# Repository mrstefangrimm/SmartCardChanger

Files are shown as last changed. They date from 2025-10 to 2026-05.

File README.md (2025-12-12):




# Smart Card Changer

The Smart Card Changer gives remote access to up to five smart cards, such as access or bank cards, using a single smart card reader. This repository contains the software, the hardware and the mechanical design files.

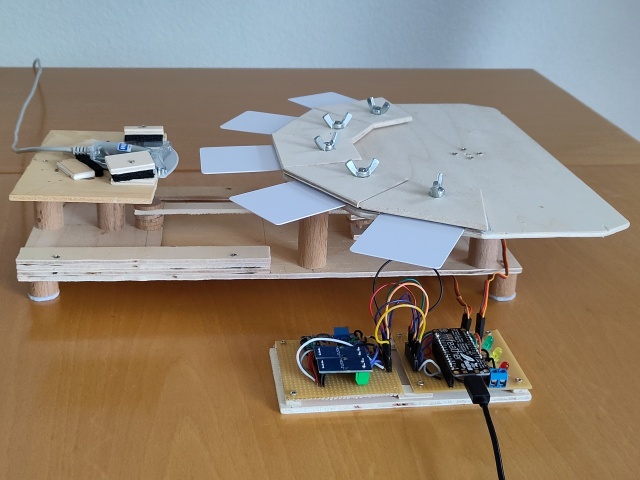
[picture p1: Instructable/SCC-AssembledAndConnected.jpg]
Assembled Smart Card Changet


## Getting Started

To use the software, you will have to build a device. How to build one is described in an [instructable](https://www.instructables.com/Smart-Card-Changer/).

## Examples

## Tests
Unit tests cover only basic functionality. The unit tests are part of the WinSccApp Visual Studio solution.

## Software Toolchain

**Built Applications**

| Application | License |
| --- | --- |
| SccApp | LGPL |
| CalibrationApp | LGPL |
| WinSccApp  | LGPL |

**Used Libraries**

| Library | Licence |
| :--- | --- |
| prfServo | LGPL |
| Adafruit MCP23017 Arduino Library | BSD |
| Adafruit BluefruitLE nRF51 | BSD |
| Arduino.h | LGPL |
| TemplateStateMachine | Apache License |
| .NET 8 | Microsoft license |

**Used Software Development Tools**

| Tool | License |
| --- | --- |
| Arduino IDE | GPL |
| Adafruit AVR Boards [Learn more](https://learn.adafruit.com/adafruit-feather-32u4-bluefruit-le/setup) | Adafruit license |
| avrdude | GPL |
| gcc | GPL |
| Visual Studio Community 2022 | Microsoft license |

## License

This is free software: you can redistribute it and/or modify it under the terms of the GNU Lesser General Public License as published by the Free Software Foundation, either version 3 of the License, or (at your option) any later version.

## Project History

The idea for the project came in mid 2025 and was first published on instructables.com in October 2025.

## Change History
See [github releases](https://github.com/mrstefangrimm/SmartCardChanger/releases).

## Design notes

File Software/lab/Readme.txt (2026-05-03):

Vipe Coded or Worse

What's vipe-coding: Fast, messy, duct‑tape code
What's worse: spaghetti coding

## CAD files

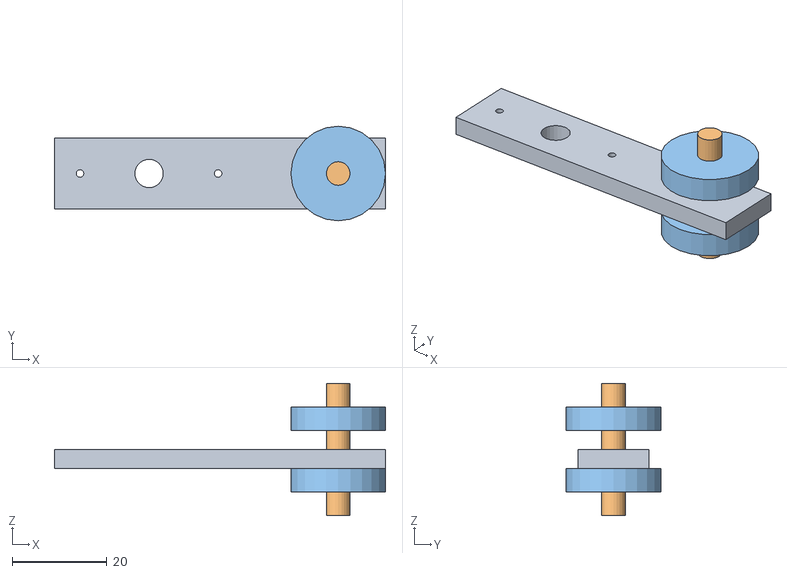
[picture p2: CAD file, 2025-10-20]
Software/src/scc/public/SCC-VirmsGroupServoArmWood.obj
70.0 x 20.0 x 28.0
SCC_ServoArm1
SCC_ServoArmJointBolt1
SCC_ServoArmJointFixation1

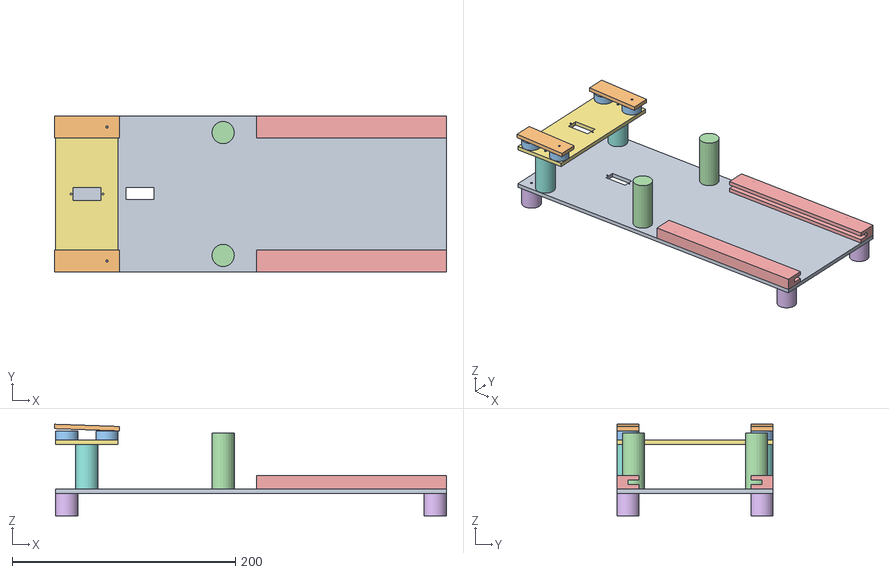
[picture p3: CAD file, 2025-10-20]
Software/src/scc/public/SCC-VirmsGroupStaticWood.obj
351.0 x 140.0 x 82.0
SCC_AdjustmentRamp_1_1
SCC_AdjustmentRamp_Distancer1
SCC_Base_Adjustment_Feet1
SCC_Base_Carriage_Rail1
SCC_Base_Feet_Wood_1_1
SCC_Rotation_Platform1
SCC_Rotation_Platform_Distancer1

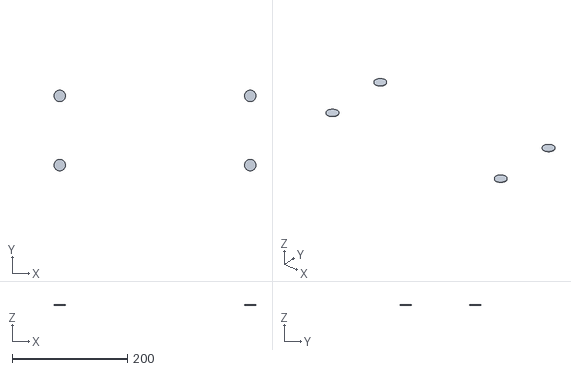
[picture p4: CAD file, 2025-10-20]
Software/src/scc/public/SCC-VirmsGroupStaticFelt.obj
350.0 x 140.0 x 2.00

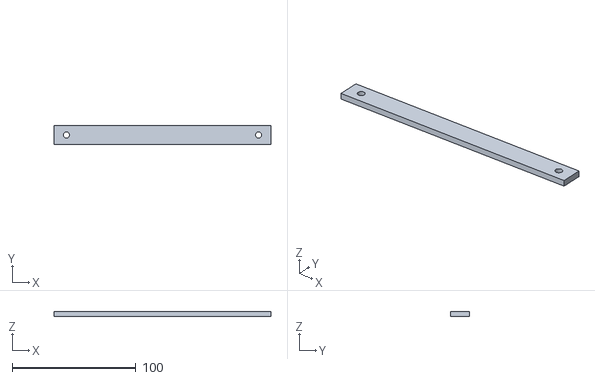
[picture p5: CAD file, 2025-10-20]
Software/src/scc/public/SCC-VirmsGroupServoArmExtensionWood.obj
175.0 x 15.0 x 4.00

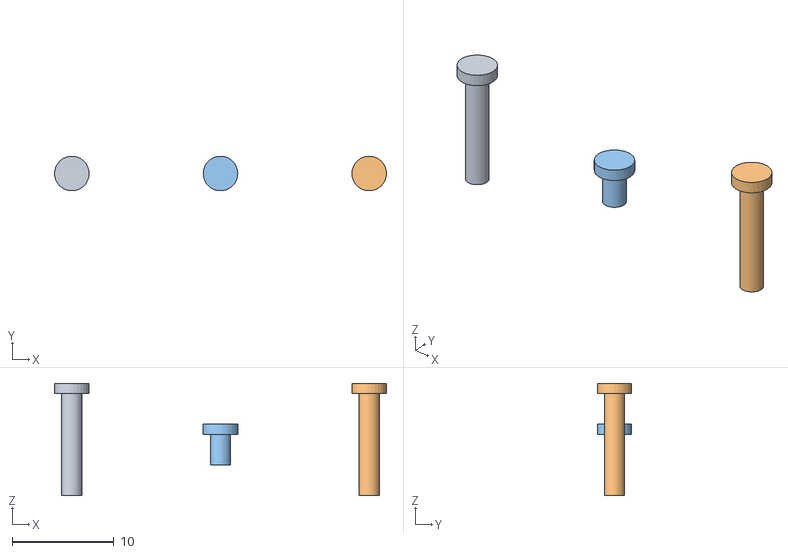
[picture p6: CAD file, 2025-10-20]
Software/src/scc/public/SCC-VirmsGroupServoArmSilver.obj
32.6 x 3.38 x 11.0
Lib_M2x10_1
Lib_M2x10_2
Lib_M2x3_1

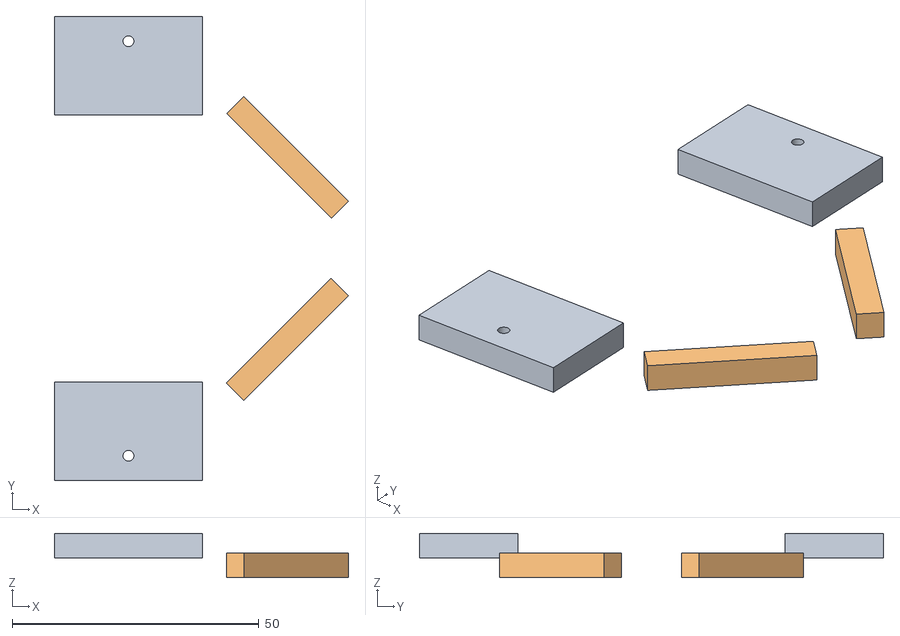
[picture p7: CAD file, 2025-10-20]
Software/src/scc/public/SCC-VirmsGroupCarriageAnthracite.obj
59.6 x 94.0 x 9.00
SCC_Carriage_Reader_Lid_Foam1
SCC_Carriage_Reader_Platform_Foam1

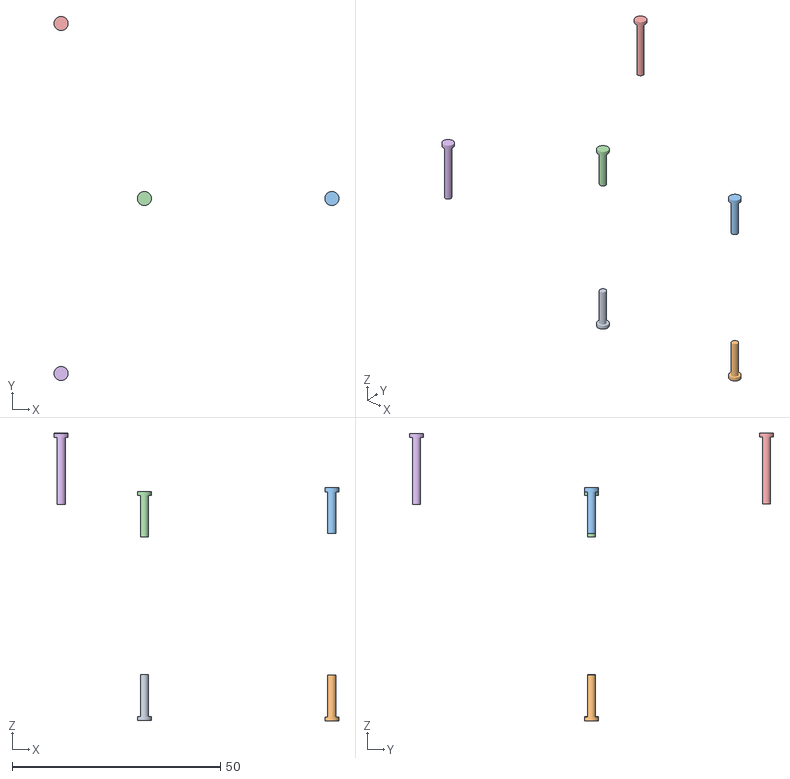
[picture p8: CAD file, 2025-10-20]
Software/src/scc/public/SCC-VirmsGroupCarriageSilver.obj
68.4 x 87.4 x 69.1
Lib_M2x10_1
Lib_M2x10_2
Lib_M2x10_3
Lib_M2x10_4
Lib_M2x16_1
Lib_M2x16_2

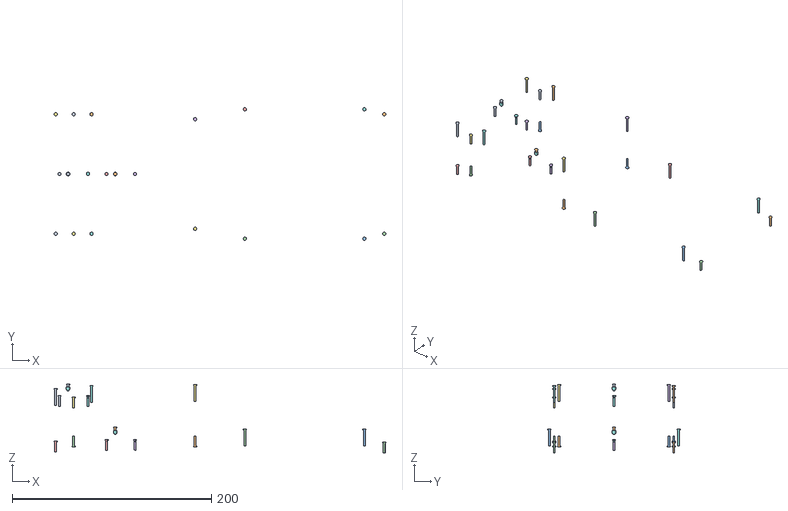
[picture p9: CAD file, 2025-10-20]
Software/src/scc/public/SCC-VirmsGroupStaticSilver.obj
333.4 x 133.4 x 69.0
Lib_M2x10_1
Lib_M2x10_10
Lib_M2x10_11
Lib_M2x10_12
Lib_M2x10_13
Lib_M2x10_14
Lib_M2x10_2
Lib_M2x10_3
Lib_M2x10_4
Lib_M2x10_5
Lib_M2x10_6
Lib_M2x10_7
Lib_M2x10_8
Lib_M2x10_9
Lib_M2x16_1
Lib_M2x16_10
Lib_M2x16_2
Lib_M2x16_3
Lib_M2x16_4
Lib_M2x16_5
Lib_M2x16_6
Lib_M2x16_7
Lib_M2x16_8
Lib_M2x16_9
Lib_M2x3_1
Lib_M2x3_2

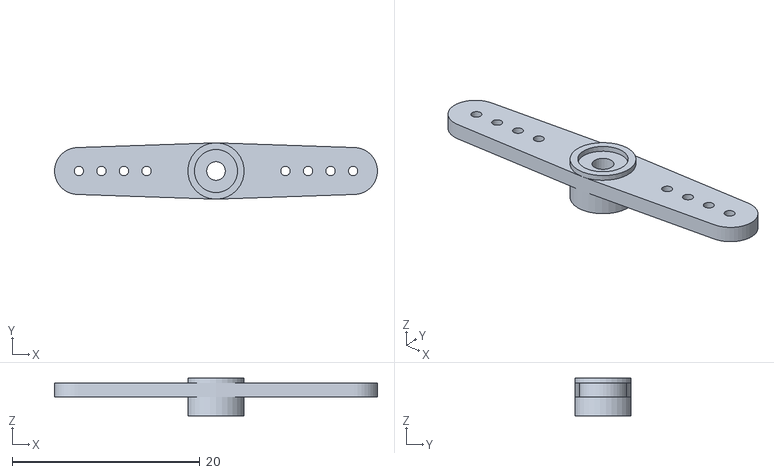
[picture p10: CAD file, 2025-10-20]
Software/src/scc/public/SCC-VirmsGroupServoArmWhite.obj
34.4 x 6.00 x 4.00

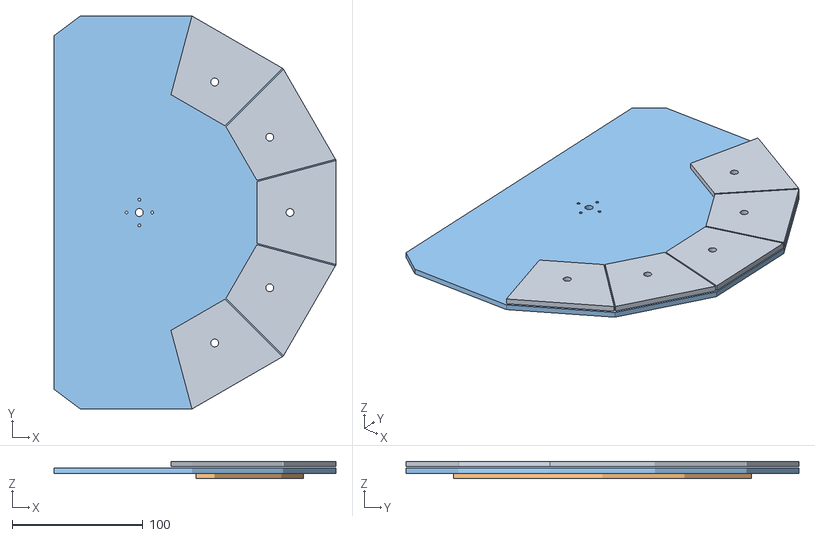
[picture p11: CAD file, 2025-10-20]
Software/src/scc/public/SCC-VirmsGroupRotatorWood.obj
215.0 x 300.0 x 13.0
SCC_Rotatator_Lid_Wood1
SCC_Rotatator_SkrewHolder1
SCC_Rotatator_Wood1

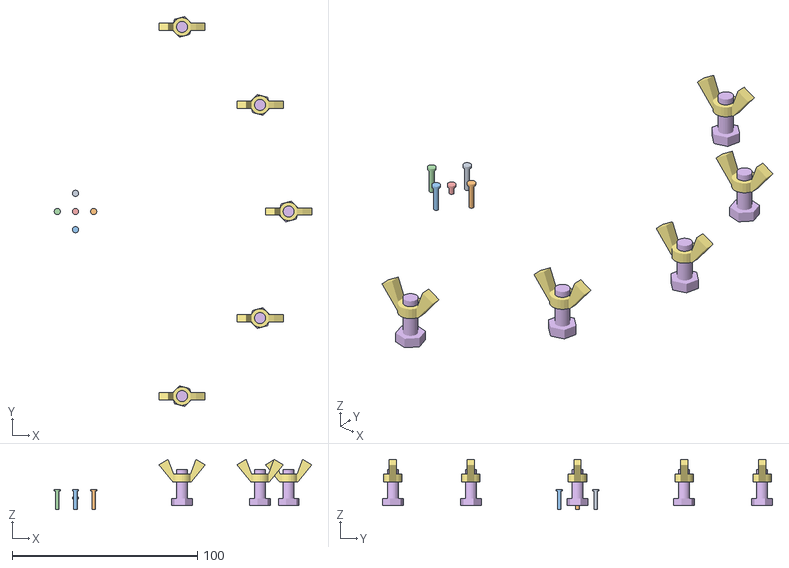
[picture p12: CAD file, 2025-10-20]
Software/src/scc/public/SCC-VirmsGroupRotatorSilver.obj
139.0 x 210.4 x 27.2
Lib_M2x10_1
Lib_M2x10_2
Lib_M2x10_3
Lib_M2x10_4
Lib_M2x3_1
SCC_Rotatator_Skrews_1_1
SCC_Rotatator_Wingnuts1

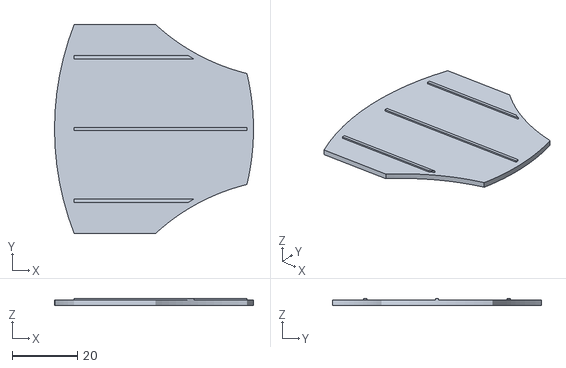
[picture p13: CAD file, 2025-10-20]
Software/src/scc/public/SCC-VirmsGroupCarriageGray.obj
61.0 x 64.0 x 2.20

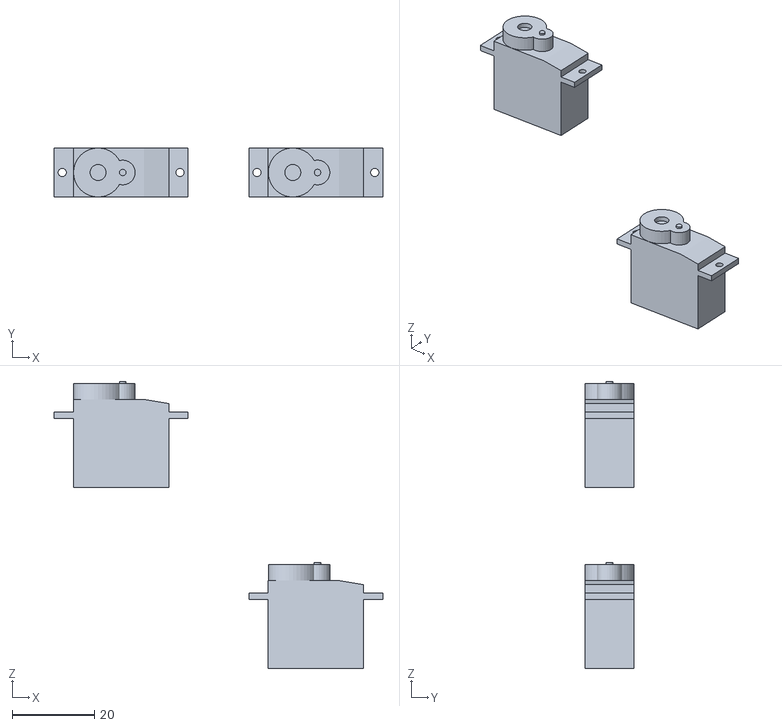
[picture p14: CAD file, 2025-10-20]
Software/src/scc/public/SCC-VirmsGroupStaticAnthracite.obj
79.9 x 12.0 x 69.8

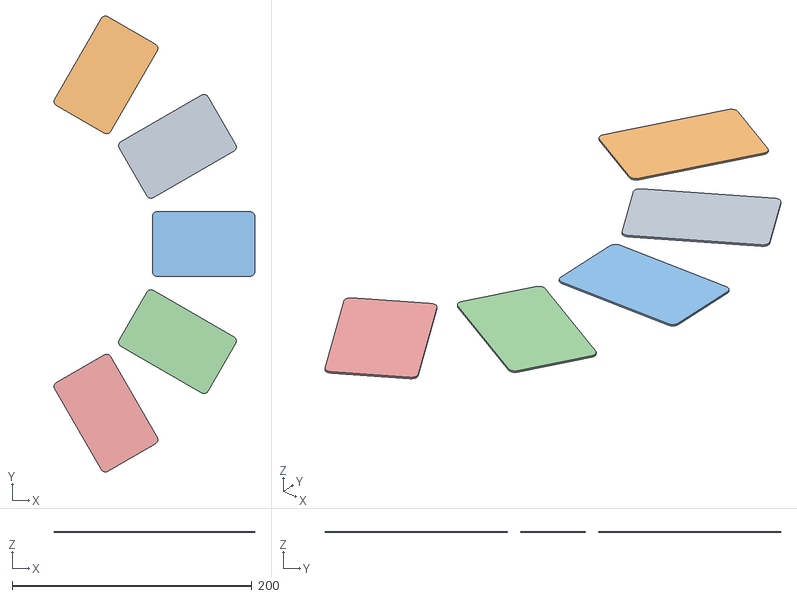
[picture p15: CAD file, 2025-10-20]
Software/src/scc/public/SCC-VirmsGroupRotatorSmartcards.obj
167.5 x 380.2 x 1.00

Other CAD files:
Software/src/scc/public/SCC-VirmsGroupRotatorWhite.obj
Software/src/scc/public/SCC-VirmsGroupCarriageTransparent.obj
Software/src/scc/public/SCC-VirmsGroupCarriageWood.obj
Software/src/scc/public/SCC-VirmsGroupCarriageGreen.obj
MechanicalDesign/SketchUp/SCC-AdjustmentRamp-Feet.skp
MechanicalDesign/SketchUp/SCC-AdjustmentRamp.skp
MechanicalDesign/SketchUp/SCC-Assemble1-Base.skp
MechanicalDesign/SketchUp/SCC-Assemble2-Carriage.skp
MechanicalDesign/SketchUp/SCC-Assemble3-ReaderPlatform.skp
MechanicalDesign/SketchUp/SCC-Assemble4-RotationPlatform.skp
MechanicalDesign/SketchUp/SCC-Assemble5-Rotatator.skp
MechanicalDesign/SketchUp/SCC-Assemble6-RotatatorLid.skp
MechanicalDesign/SketchUp/SCC-Assembled1-Base.skp
MechanicalDesign/SketchUp/SCC-Base-Adjustment-Feet.skp
MechanicalDesign/SketchUp/SCC-Base-Carriage-Rail.skp
MechanicalDesign/SketchUp/SCC-Base-Feet-Felt.skp
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

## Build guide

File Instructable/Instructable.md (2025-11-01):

# Smart Card Changer

## Introduction

[Vimeo](https://vimeo.com/1132590118?fl=pl&fe=sh)

[Youtube](https://youtu.be/RYG996cEZuI)

The Smart Card Changer gives remote access to up to five smart cards, such as access or bank cards, using a single smart card reader. Via a Bluetooth connection, you can conveniently insert or eject cards with your smartphone. The smart card changer is especially useful when the reader is connected to a PC that is out of reach.

The smart card changer has three components:

- The Mechanical Structure
- The Control Module
- The Overload Protection Module

The mechanical structure is constructed using basswood sheets and wooden cylinders. It uses two micro servo motors for a linear and a rotational motion. Check out the [interactive 3D model](smartcc.netlify.app).

The control module uses an Adafruit BLE feather board, which controls the two servo motors and is used for the Bluetooth connection with a smartphone.

The overload protection module monitors the electrical current drawn by the servo motors and automatically interrupts the circuit in the event of an overload.

Tooling
- A small lathe to cut the wooden cylinders to length
- Fretsaw or carpet knife to cut the basswood sheets
- Soldering station

The material costs are approximately $120.

## Supplies

- 1 HID  Omnikey USB smart cards reader/writer, version 3021
- 1 Adafruit Feather 32u4 Bluefruit LE
- 2 PDI-9180MG micro servo motor

**Mechanical Structure**

- 2 basswood sheets, 4 mm thick, DIN A3
- 1 prototyping board, approximately 10 cm x 20 cm
- 1 cardboard, DIN A4
- 4 felt mats with 20 mm diameter
- anti-static foam, approximately 7 cm x 7 cm
- 5 hex screws M6 x 18 mm
- 5 wing nuts M6
- 24 screws M2 x 10 mm
- 12 screws M2 x 16 mm

**Control Module**

- 3 LEDs in different colors
 - 3 resistors 100 ohm
 - male headers with 32 pins
 - female headers for 8 pins
 - 1 power connector for 5V DC

**Overload Protection Module**

 - 1 step-up converter. This is required because the transistor requires 5 VDC and the Adafruit feather provides 3.3 VDC
 - 1 transistor IRF520 (or similar)
 - 2 ACS712 current measurement modules
 - 1 female header for 8 pins the overload protection module

## Step 1: Basic Structure

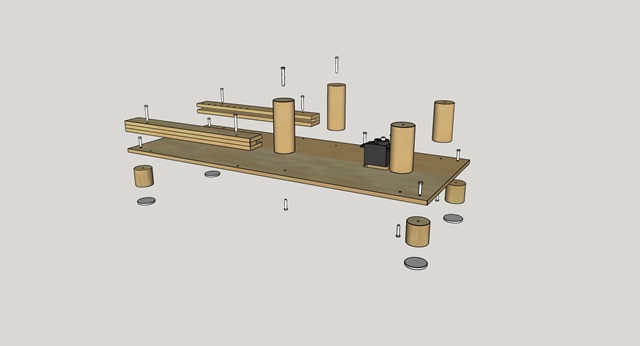
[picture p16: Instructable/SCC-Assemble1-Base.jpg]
SCC-Assemble1-Base


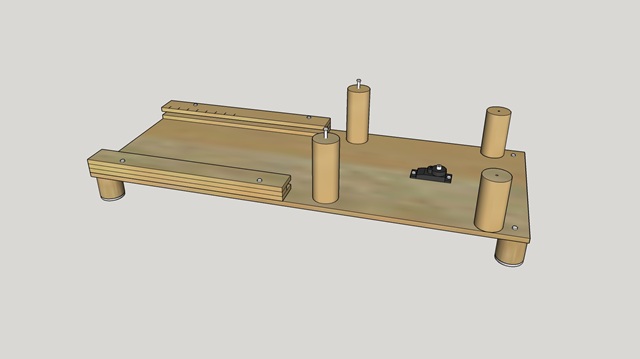
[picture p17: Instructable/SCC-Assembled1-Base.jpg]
SCC-Assembled1-Base


The basic structure is the structural base for both the carriage and the rotator.

On the left side in the image are the rails for the carriage. The two cylinders on the right side are for the rotator platform. The two cylinders in the center are used to adjust the height of the rotator.

Dimensions and Positions:

- 2 cylinders with the height of 50 mm. They are located 15 mm from the longitudinal side and 150 mm from the rear side
- 2 cylinders with the height of 40 mm. They are located 10mm from the longitudinal side and 28 mm from the rear side
- 4 cylinders with the height of 20 mm. They are located 10 mm from the longitudinal and 10 mm from the front sides
- A basswood piece 350 mm x 140 mm. The slot for the servo motor has a size of 25 mm x 12 mm and the distance to the rear side is 63 mm
- 4 basswood pieces 170 mm x 20 mm
- 2 basswood pieces 170 mm x 10 mm
- 4 felt mats with 20 mm diameter

## Step 2: Carriage and Servo Arm

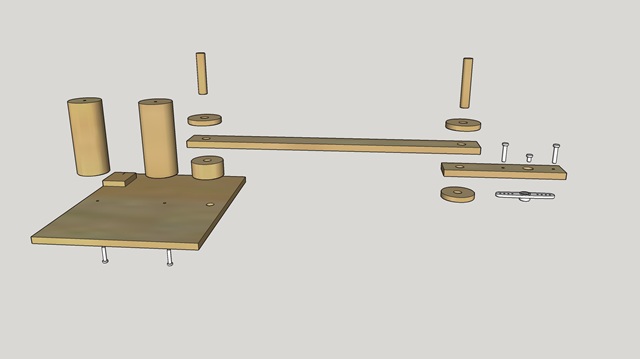
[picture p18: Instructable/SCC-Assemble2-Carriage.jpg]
SCC-Assemble2-Carriage


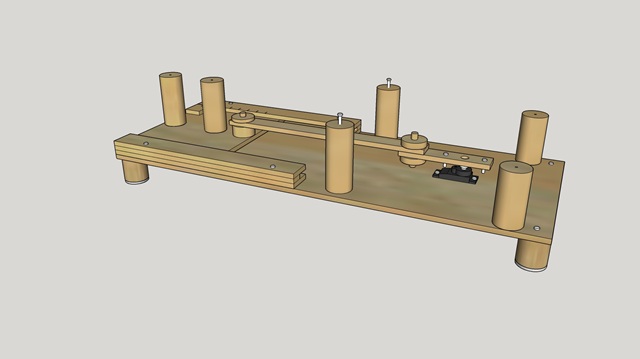
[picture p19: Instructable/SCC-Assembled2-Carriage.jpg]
SCC-Assembled2-Carriage


The carriage is the part that slides in the rails of the basic structure. In the center of the image is the servo arm extension and on the right the servo arm. The servo arm is mounted onto the servo motor.

Dimensions and Positions:

- 2 cylinders with the height of 46 mm. They are located 10 mm and 55 mm from the front side
- 1 cylinder with the height of 9.7 mm. It is located 10 mm from the front side. The diameter of the hole in the center is 5.2 mm
- 3 cylinders with the the height of 3 mm. The diameter of the hole in the center is 5 mm
- 2 bolts with a 5 mm diameter and a length of 24 mm
- 1 basswood piece 119 mm x 95 mm. The hole for the spacer is locate 10 mm from the front side and has a diameter of 5 mm
- 1 basswood piece 175 mm x 15 mm. The holes are located 10 mm from the front sides with a diameter of 5.2 mm
- 1 basswood piece 70 mm x 15 mm. One hole is located 10 mm from the front side with a diameter of 5.2 mm. One hole is located 20 mm from the front side and has a diameter of 6 mm

## Step 3: Card Reader Platform

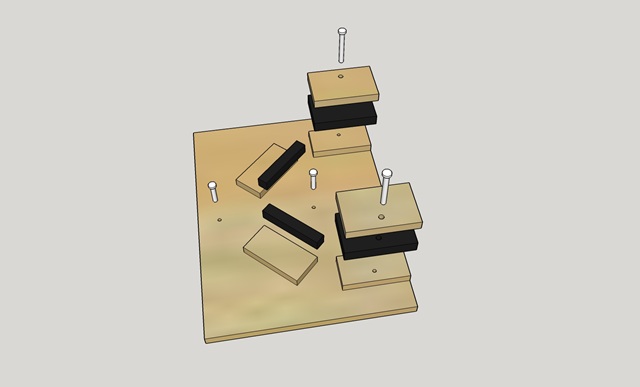
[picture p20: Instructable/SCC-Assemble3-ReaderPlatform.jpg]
SCC-Assemble3-ReaderPlatform


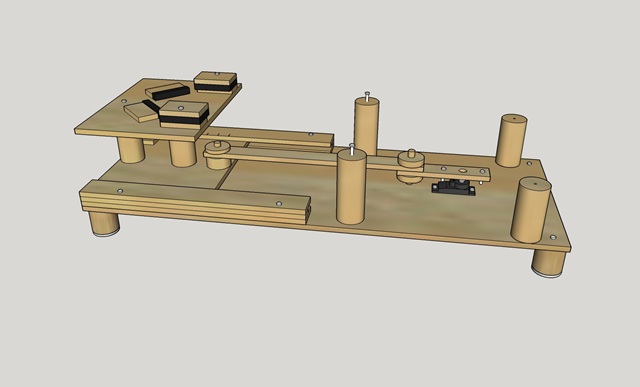
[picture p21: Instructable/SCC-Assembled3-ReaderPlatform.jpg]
SCC-Assembled3-ReaderPlatform


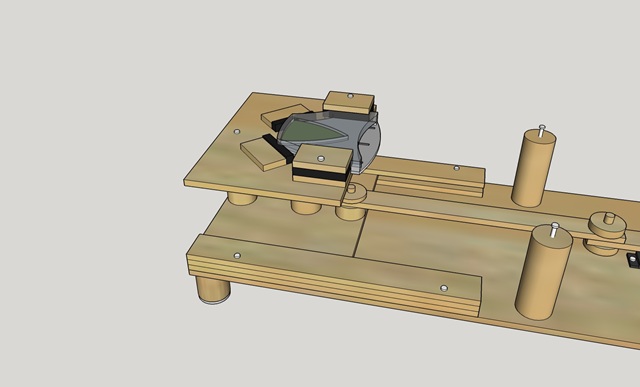
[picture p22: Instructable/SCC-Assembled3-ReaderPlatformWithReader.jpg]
SCC-Assembled3-ReaderPlatformWithReader


The card reader platform is used for the Omnikey Smart Card Reader and is mounted onto the carriage assembly. The black segments in the image are anti-static foam and used to fixate the card reader. Anti-static foam is commonly used for packaging integrated circuits.

Dimensions and Positions:

- 1 basswood piece 120 mm x 90 mm
- 4 basswood pieces 30 mm x 15 mm. 2 pieces are located at the front side with a in-between distance of 64 mm.  2 pieces are located 38 mm from the front side in a 45 degree angle
-  2 basswood pieces 30 mm x 20 mm
- 4 pieces of anti-static foam

## Step 4: Rotator Platform

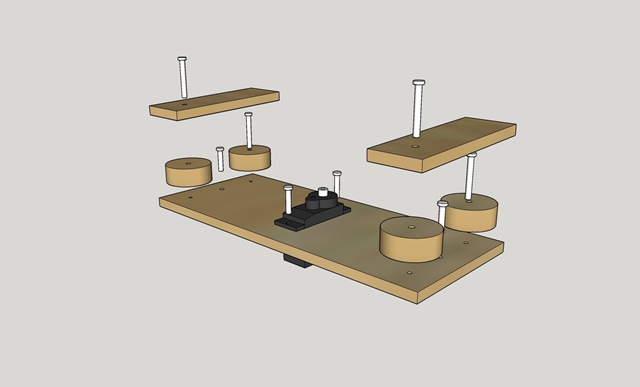
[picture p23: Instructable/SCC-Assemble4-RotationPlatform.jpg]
SCC-Assemble4-RotationPlatform


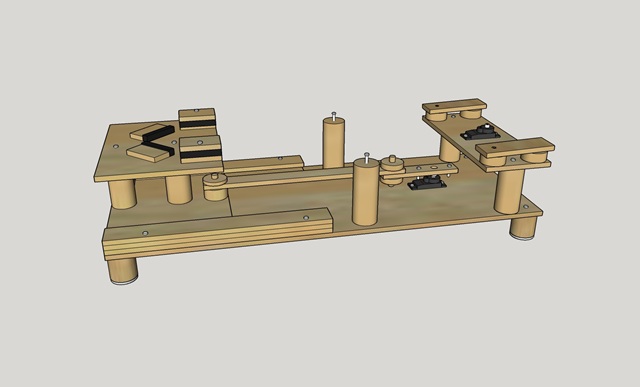
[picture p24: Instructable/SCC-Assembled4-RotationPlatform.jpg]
SCC-Assembled4-RotatationPlatform


The rotator platform is mounted onto the basic structure. It has a ramp on both sides to mechanically adjust the height of the rotator.

Dimensions and Positions:

- 4 cylinders with the height of 8 mm. The cylinders are located 10 mm from the edge.
- 2 basswood pieces 58 mm x 20 mm
- 1 basswood piece 140 mm x 56 mm. The slot for the servo motor has a size of 25 mm x 12 mm and the distance to both the rear and the front side is 15.5 mm

## Step 5: Rotator

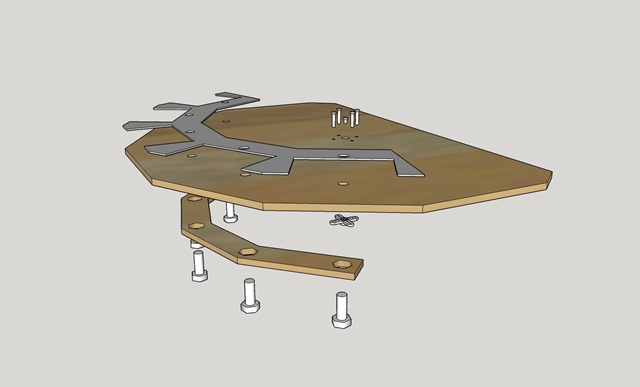
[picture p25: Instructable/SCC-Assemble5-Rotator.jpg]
SCC-Assemble5-Rotator


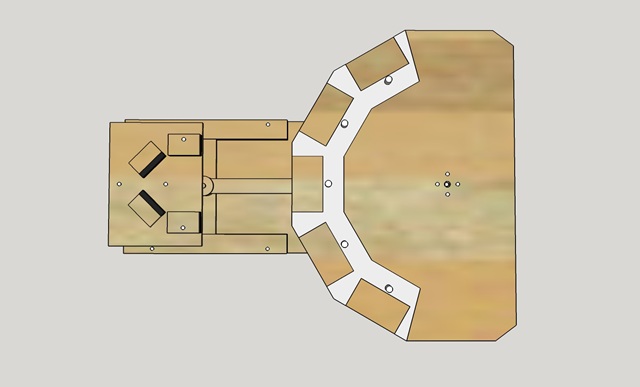
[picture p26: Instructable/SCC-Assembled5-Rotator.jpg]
SCC-Assembled5-Rotator


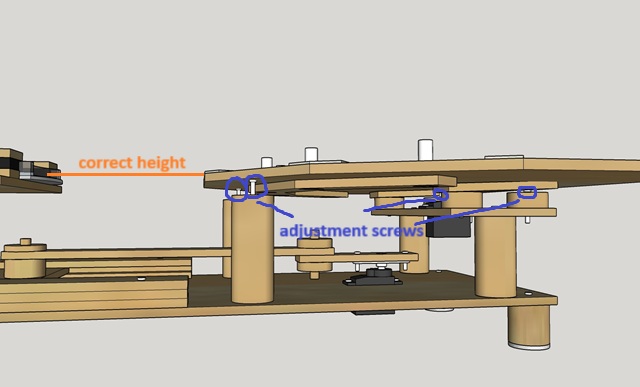
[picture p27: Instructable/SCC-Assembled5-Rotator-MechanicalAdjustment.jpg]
SCC-Assembled5-Rotator-MechanicalAdjustment


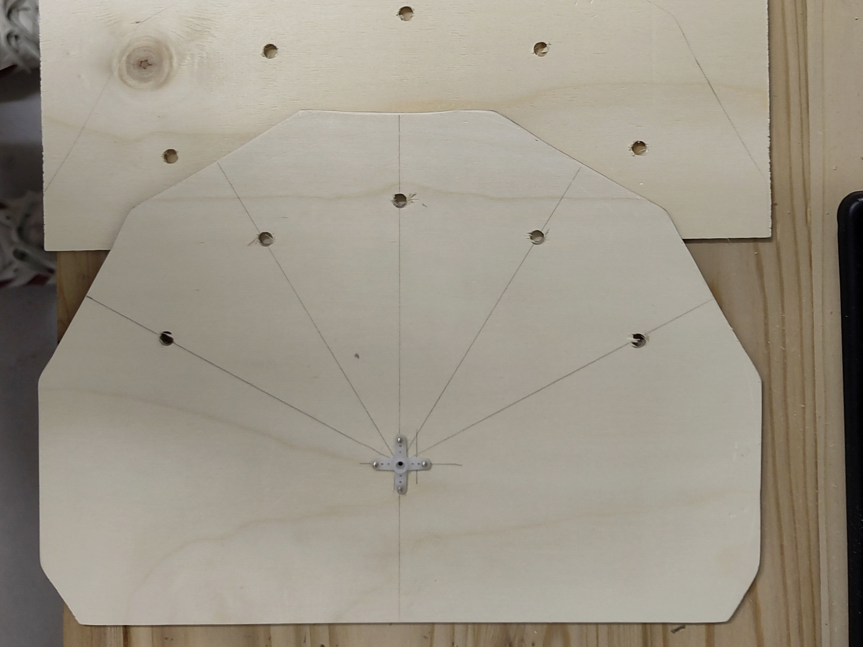
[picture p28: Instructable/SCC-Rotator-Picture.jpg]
SCC-Rotator-Picture


The rotator is mounted onto the rotator platform. The angle between the card slots is 30 degrees. The card slots are cut out of cardboard which is glued onto the rotator. The cards are fixated with hexagon screws.

The mechanical adjustment is part of this step. Use the 4 adjustment screws until each card slot has the same height as the card reader mouth.

Dimensions and Positions:

- 1 large basswood piece 300 mm x 215 mm. The rotation center is located 65 mm from the rear side. The radius for the card slots is 150 mm (215 - 65). The card fixation screws are located 35 mm from the front side for each card slot.
- 1 cardboard with the cut out card slots. The slots have a dimension of 54 mm x 30 mm

## Step 6: Rotator Lids

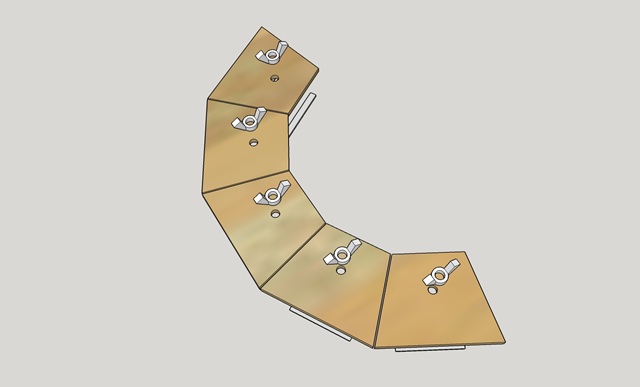
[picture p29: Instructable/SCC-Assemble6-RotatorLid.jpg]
SCC-Assemble6-RotatorLid


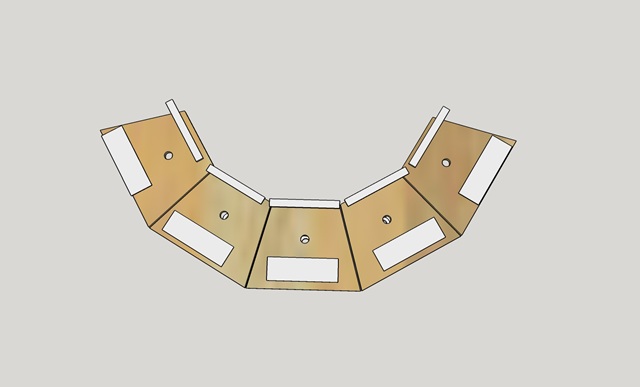
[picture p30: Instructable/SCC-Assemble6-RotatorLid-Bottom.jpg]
SCC-Assemble6-RotatorLid-Bottom


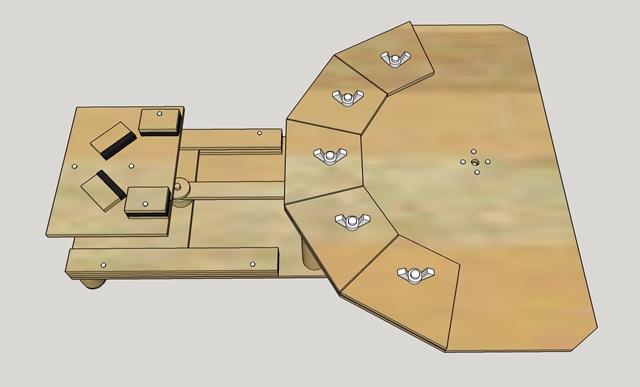
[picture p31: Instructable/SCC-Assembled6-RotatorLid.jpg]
SCC-Assembled6-RotatorLid


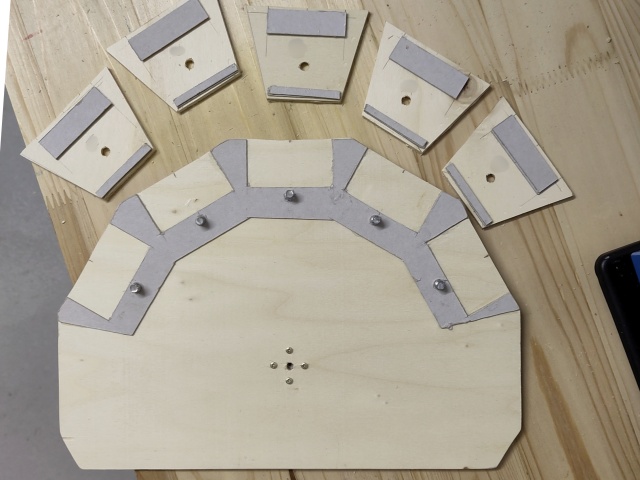
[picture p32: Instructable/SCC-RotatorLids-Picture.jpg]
SCC-RotatorLids-Picture


With the rotator lid, the cards are fixated to the rotator. Cardboard pieces are glued to the lids. The cardboard pieces prevent the card from being pulled out by the reader.

Dimensions and Positions:

- 5 basswood pieces 60 mm x 79 mm. The angle of the side edges is 15 degrees towards the rotation center
- 5 cardboard pieces 46 mm x 15 mm
- 10 cardboard pieces 46 mm x 5 mm

## Step 7: Control Module

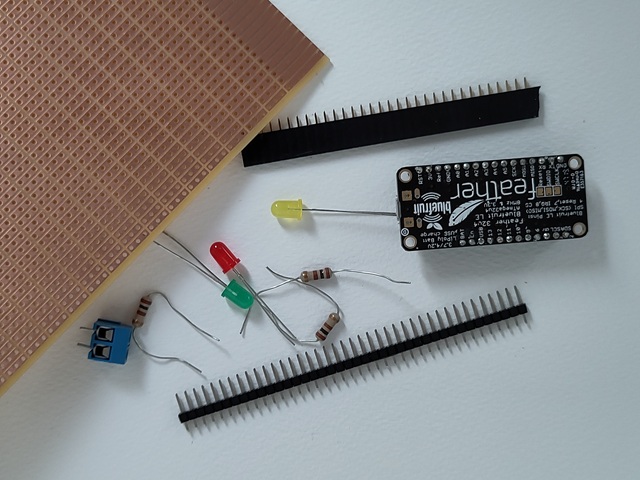
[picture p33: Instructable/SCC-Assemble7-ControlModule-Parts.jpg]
SCC-Assemble7-ControlModule-Parts


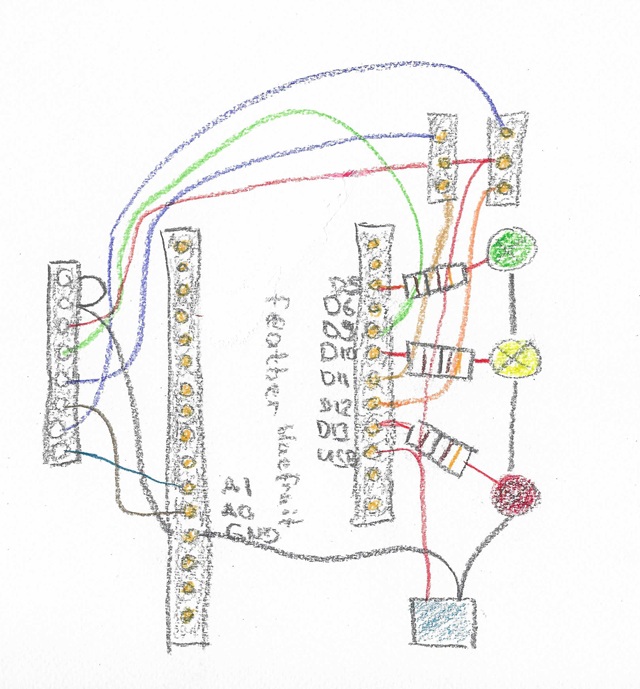
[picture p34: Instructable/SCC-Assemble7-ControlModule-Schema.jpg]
SCC-Assemble7-ControlModule-Schema


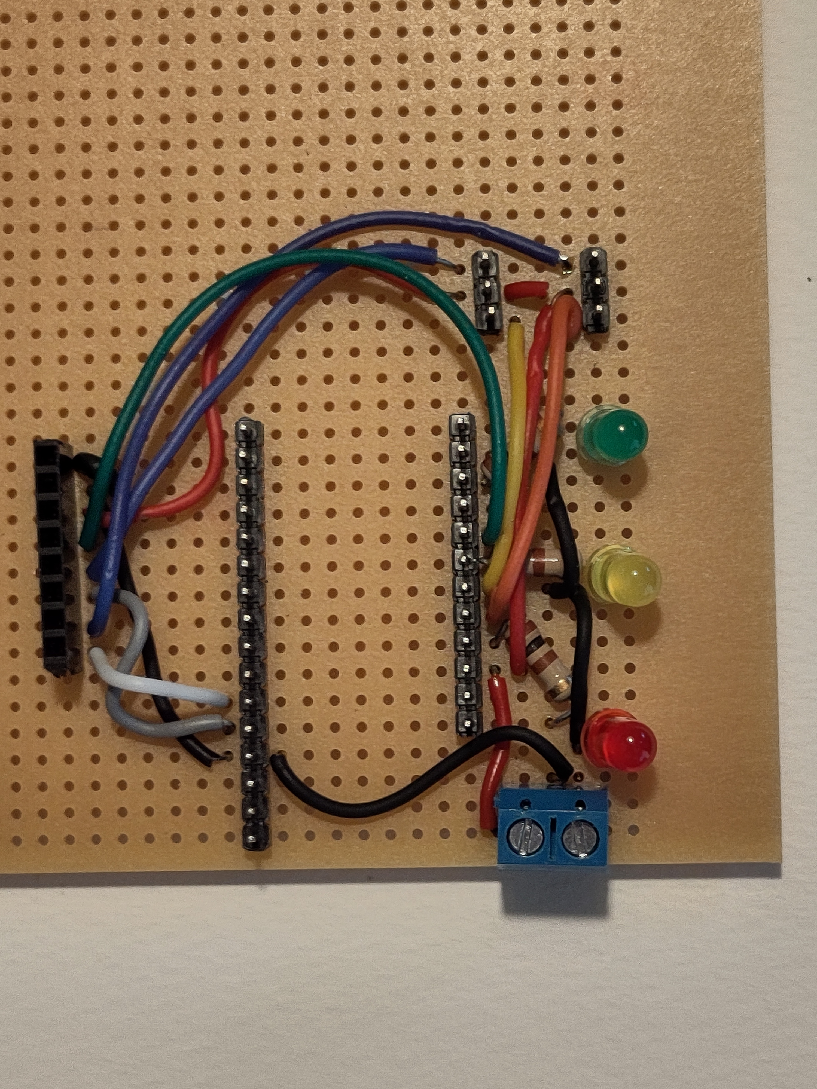
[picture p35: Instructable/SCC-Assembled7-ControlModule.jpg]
SCC-Assembled7-ControlModule


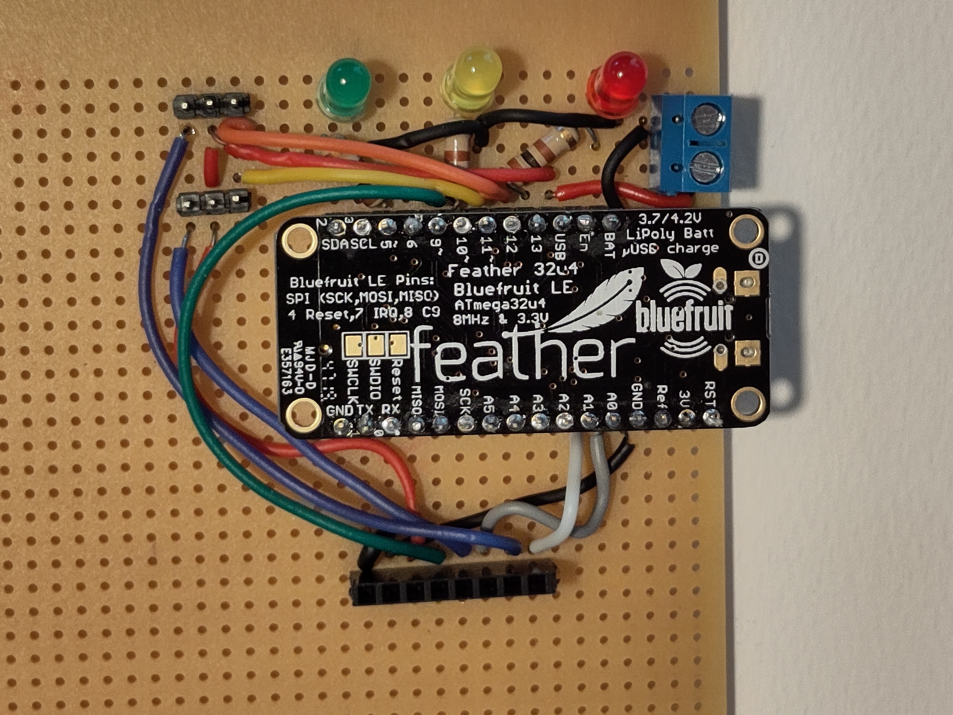
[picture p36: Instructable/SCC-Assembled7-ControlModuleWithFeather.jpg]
SCC-Assembled7-ControlModuleWithFeather


The smart card changer is already operational with the control module. In the next step, the control module is tested and the smart card changer is calibrated

Parts

 - 3 LEDs in different colors
 - 3 resistors 100 ohm
 - 2 male headers with 3 pins to connect the servo motors
 - 1 male header with 12 pins
 - 1 male header with 17 pins
 - 1 female header for 8 pins the overload protection module
 - 1 power connector for 5V DC

## Step 8: Test and Calibrate

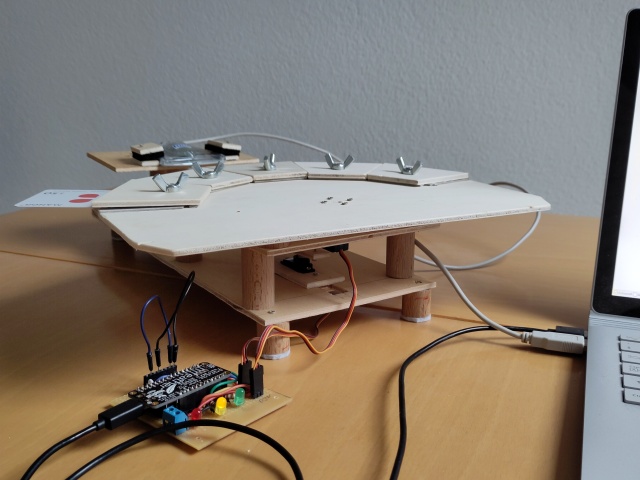
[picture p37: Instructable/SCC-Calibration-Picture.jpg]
SCC-Calibration-Picture


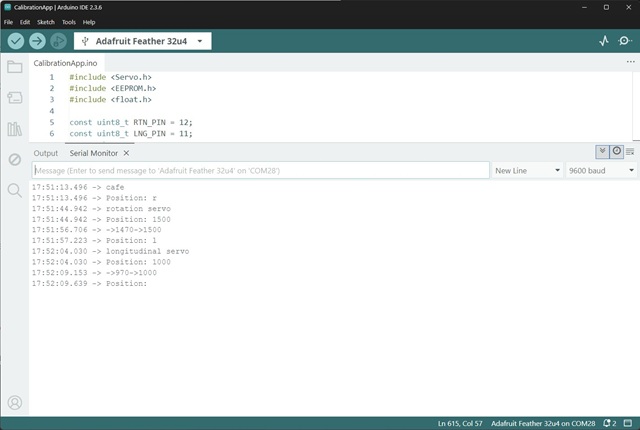
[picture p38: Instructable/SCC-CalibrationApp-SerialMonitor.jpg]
SCC-CalibrationApp-SerialMonitor


To operate the smart card changer without the overload protection module, add a shortcut wire as shown in the image above. Power is supplied to the smart card changer via a USB connection to the host PC..

Download and unzip the latest release from [github](https://github.com/mrstefangrimm/SmartCardChanger/releases). Open the sketch *CalibrationApp.ino* in the Arduino IDE upload it to the control module.

Plug in the servo motors and the servo motors move to the initial position.

In the Arduino IDE, open the Serial Monitor.

1. The prompt shows "Erase memory? [y/n]". The calibration is stored on the EEPROM - existing data is overwritten. Choose "y" to continue
2. "Position: ". Type in "r" for *rotation servo*  
3. "Position: ". Type in "1500". The rotator moves to a new position
4. "Position: ". Type in "l" for *longitudinal servo*  
5. "Position: ". Type in 1000. The carriage moves to a new position

**Longitudinal Calibration**

Choose "l" for *longitudinal servo* and position the carriage to fully retracted, then 1 cm, 2 cm, 3 cm, ... , 7 cm towards the rotator. Write down the position values for each step.

| mm | servo |
| ---- | ----- |
| 0 | 950 |
| 10 | 1090 |
| 20 | 1180 |
| 40 | 1330 |
| 60 | 1505 |
| 70 | 1630 |
> Example calibration longitudinal axis, 16. Aug. 2025

The calculated polynomial coefficients  (polynomial of 3 degree)

| polynomial degree | coefficient |
| ---- | ----- |
| 0 | 9.5199345532256200e+002 |
| 1 | 1.5448059970614935e+001 |
| 2 | -2.3899425671160265e-001 |
| 3 | -2.3899425671160265e-001 |
> Example coefficients longitudinal axis, 16. Aug. 2025

**Rotational Calibration**

For the rotational axis we cannot overlook the mechanical play (backlash).

Choose "r" for *rotation servo*. Calibrate the card slots in clockwise and counter clockwise direction. Write down the position values for each step. The backlash is the ccw position minus the cw position.

| degrees | servo |
| ---- | ----- |
| 30 | 1105 |
| 60 | 1270 |
| 90 | 1435 |
| 120 | 1602 |
| 150 | 1765 |
> Example calibration rotational axis clockwise, 16. Aug. 2025

| degrees | servo | backlash |
| ---- | ----- | --- |
| 30 | 1085 | -20 |
| 60 | 1245 | -25 |
| 90 | 1410 | - 25 |
| 120 | 1585  | -17|
| 150 | 1745  | - 20|
> Example calibration rotational axis counter clockwise, 16. Aug. 2025

The calculated polynomial coefficients for the clockwise rotation  (polynomial of 3 degree)
| polynomial degree | coefficient |
| ---- | ----- |
| 0 | 9.4440000000000009e+002 |
| 1 | 5.2730158730158729e+000 |
| 2 | 3.1746031746031746e-003 |
| 3 | -1.2345679012345678e-005 |
> Example coefficients rotational axis, 16. Aug. 2025

The calculated polynomial coefficients for the counter clockwise backlash (polynomial of 2 degree)
| polynomial degree | coefficient |
| ---- | ----- |
| 0 | -3.3799999999999997e+001 |
| 1 | 4.0761904761904760e-001, |
| 2 | -6.3492063492063492e-004 |
> Example coefficients backlash, 16. Aug. 2025

Back in the Serial Monitor, the polynomial coefficients are stored in the EEPROM

- "Position: ". Type in "w" for *write to EEPROM*. Follow the instructions on save the calibration data to the EEPROM.

## Step 9: Overload Protection Module

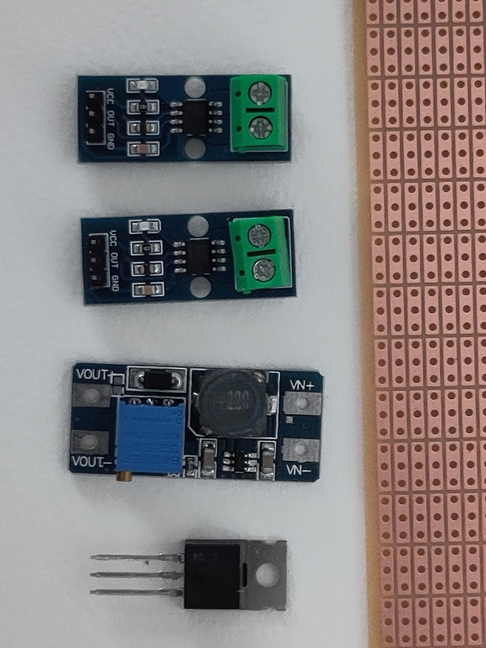
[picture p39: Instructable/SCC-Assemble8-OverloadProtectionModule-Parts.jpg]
SCC-Assemble8-OverloadProtectionModule-Parts


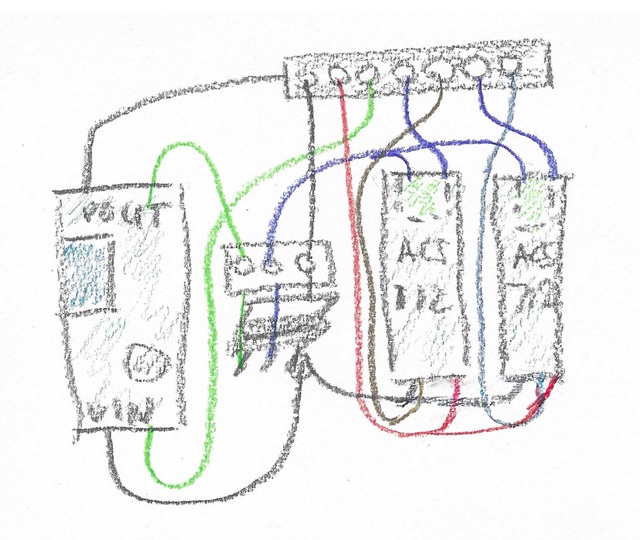
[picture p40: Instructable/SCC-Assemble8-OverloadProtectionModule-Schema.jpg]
SCC-Assemble8-OverloadProtectionModule-Schema


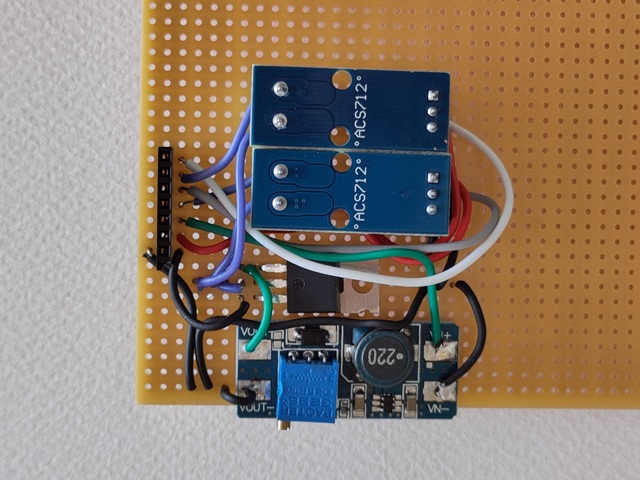
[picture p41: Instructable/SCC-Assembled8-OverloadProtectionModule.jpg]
SCC-Assembled8-OverloadProtectionModule


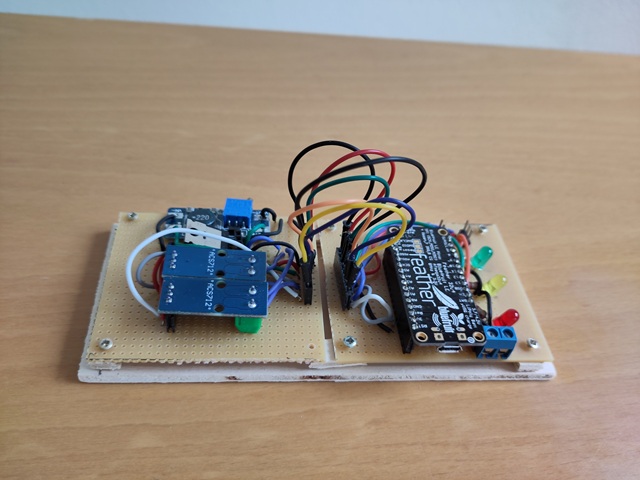
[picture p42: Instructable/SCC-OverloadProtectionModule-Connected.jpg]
SCC-OverloadProtectionModule-Connected


The overload protection module is optional - smart card changer can be operated without it. Without the protection module, the smart cards could be damaged though.

Then connect the overload module to the control module.

Parts:

 - 1 step-up converter. This is required because the transistor requires 5 VDC and the Adafruit feather provides 3.3 VDC
 - 1 transistor IRF520 (or similar)
 - 2 ACS712 current measurement modules
 - 1 female header for 8 pins the overload protection module

## Step 10: Test and Operate

SCC-AssembledAndConnected

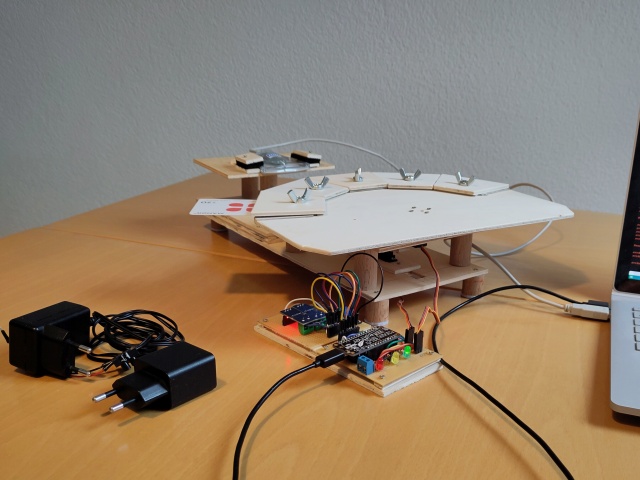
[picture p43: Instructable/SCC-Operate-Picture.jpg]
SCC-Operate-Picture


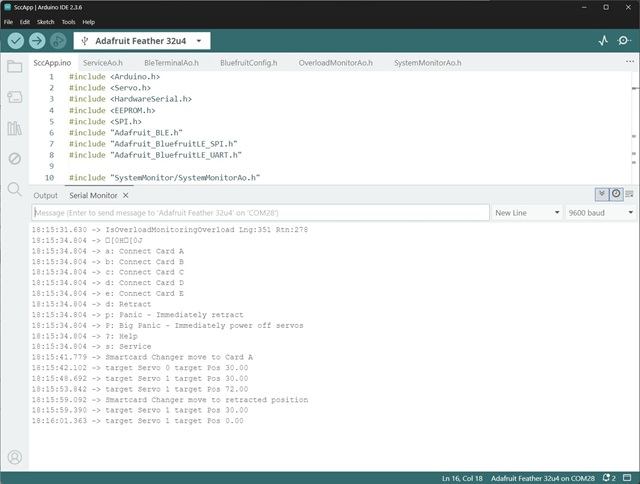
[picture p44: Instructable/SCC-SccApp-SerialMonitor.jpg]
SCC-SccApp-SerialMonitor


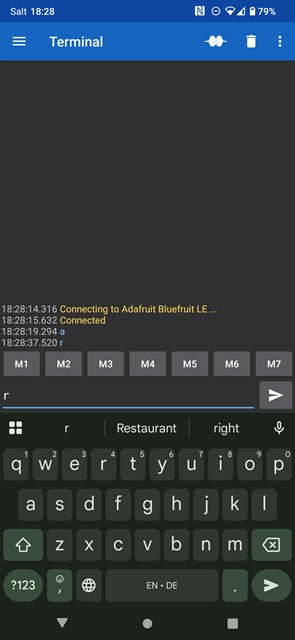
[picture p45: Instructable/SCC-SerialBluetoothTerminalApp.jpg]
SCC-SerialBluetoothTerminalApp


The smart card changer can be powered via three options:

- USB connection to the PC.
- USB cable linked to an AC/DC power adapter
- Through dedicated power plugs. 

To use it with Bluetooth, the smart card changer functions independently and does not require a physical connection to the PC.

Download and unzip the latest release from [github](https://github.com/mrstefangrimm/SmartCardChanger/releases). Copy the content of the libraries folder into *Documents\Arduino\libraries*. Open the sketch *SccApp.ino* in the Arduino IDE upload it to the control module.

**Test with USB**

In the Arduino IDE, open the Serial Monitor.

1. Erase the content of the serial monitor and type in "?" for help. The available commands are shown

2. Type in "a" to insert the card in the first card slot. The rotator rotates to the first card slot and the carriage moves forward.

3. Type in "r" to retract the carriage. The carriage moves to the initial position.

**Test with Bluetooth**

Install a Bluetooth (BLE) compatible terminal app on your smart phone to use the smart card changer with Bluetooth. These two apps have been verified to work reliably:

- Serial Bluetooth Terminal
- Bluefruit Connect from Adafruit

When connected, send an "a" to insert the smart card in the first slot. Send "r" to retract the carriage to the initial position. The slots are "a", "b", "c", "d", "e". If you send a "p" for *panic*, the carriage goes instantly to the initial position.

That is the Smart Card Changer.

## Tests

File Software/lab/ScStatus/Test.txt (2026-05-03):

docker build . -t hall:o
docker run -u root --privileged -d --name hall -p 8080:8080 -v /var/run/pcscd/pcscd.comm:/var/run/pcscd/pcscd.comm --device /dev/bus/usb hall:o

--device=/dev/ttyUSB0

bash
curl -X GET http://localhost:8080/status

FROM mcr.microsoft.com/dotnet/runtime:8.0-windowsservercore-ltsc2022

Step 1 — Install OpenSC on Windows

Download OpenSC for Windows:

https://github.com/OpenSC/OpenSC/releases (github.com in Bing)

Install it — it includes:

    pcsc-proxy.exe (server)

    pcsc-spy tools

    Smart card middleware

🟦 Step 2 — Start the PC/SC proxy server on Windows

Run:
powershell

pcsc-proxy.exe --server 0.0.0.0:35963

This exposes Windows PC/SC over TCP port 35963.

You can also run it as a background service.
🟦 Step 3 — Install pcsc-lite + proxy driver in your Linux container

In your Dockerfile:
dockerfile

RUN apt-get update && apt-get install -y pcscd libpcsclite1 opensc

OpenSC on Linux includes the proxy driver.
🟦 Step 4 — Configure pcscd to use the proxy driver

Create:

/etc/reader.conf.d/proxy.conf
Code

FRIENDLYNAME "PCSC Proxy"
DEVICENAME   "pcsc-proxy"
LIBPATH      "/usr/lib/x86_64-linux-gnu/opensc-pkcs11.so"
CHANNELID    "tcp:host.docker.internal:35963"

Important:

    host.docker.internal works in Docker Desktop

    Port must match the Windows proxy server

🟦 Step 5 — Start pcscd inside the container

Use your entrypoint script:
bash

pcscd --foreground --auto-exit --disable-polkit &
sleep 1
dotnet YourApp.dll

🟦 Step 6 — Test inside the container

Run:
Code

pcsc_scan

You should see your Windows smart card reader appear inside the Linux container.
🎉 Result

Your Linux container now uses the Windows smart card reader, without USB passthrough, without /dev/bus/usb, and without hardware access issues.

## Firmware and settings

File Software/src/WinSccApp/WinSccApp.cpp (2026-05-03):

#include <iostream>
#include <cassert>
#include <chrono>
#include <thread>
#include <conio.h>

#define F
#define PROGMEM
const uint8_t OUTPUT = 0;
const uint8_t LOW = 0;
const uint8_t HIGH = 0;
static const uint8_t A0 = 18;
static const uint8_t A1 = 19;
enum class SerialFakeMode { BIN, HEX };
void pinMode(uint8_t pin, uint8_t mode) {}
void delay(uint32_t ms) {}
void digitalWrite(uint8_t pin, uint8_t mode) {}
int analogRead(uint8_t pin) { return 780; }

using namespace std;

#include "SystemMonitor/SystemMonitorAo.h"
#include "PulsWidthTransmitter/PulsWidthTransmitterAo.h"
#include "Trajectory/TrajectoryAo.h"
#include "UsbTerminal/UsbTerminalAo.h"
#include "BleTerminal/BleTerminalAo.h"
#include "OverloadMonitor/OverloadMonitorAo.h"
#include "Service/ServiceAo.h"
#include "Shared/Messages.h"
#include "Shared/Singleton.h"
#include "Shared/ConfigurationData.h"


void rtassert(bool condition) { assert(condition); }

struct DummyString {
  DummyString(char* ch) {

  }
  const char* c_str() const { return ""; }
  int toInt() const { return 1400; }
};

struct DummySerial {
  void begin(unsigned long baud) {}
  int available() { return _kbhit(); }
  int read() { return _getch(); }
  DummyString readString() {
    _cgets_s(_buf, 50, &_pos);
    return DummyString(_buf);
  }
  void print(const char* ch) {
    std::cout << ch;
  }
  void print(char ch) {
    std::cout << ch;
  }
  void print(char ch, uint8_t) {
    char str[2] = { ch, '\0' };
    std::cout << str;
  }
  void print(int val) {
    std::cout << val;
  }
  void print(float val) {
    std::cout << val << std::endl;
  }
  void println() {
    std::cout << std::endl;
  }
  void println(const char* ch) {
    std::cout << ch << std::endl;
  }
  void println(const char* ch, SerialFakeMode) {
    std::cout << ch << std::endl;
  }
  void println(int val) {
    std::cout << val << std::endl;
  }
  void println(float val, uint8_t precision) {
    std::cout << val << std::endl;
  }
  operator bool() { return true; }

private:
  char _buf[50];
  size_t _pos;
};

struct DummyBle {
  bool begin(bool v) { return false; }
  bool isConnected() { return false; }
  size_t println(const char[]) { return 0; }
  uint16_t readline() { return 0; }
  bool waitForOK() { return false; }
  bool factoryReset() { return false; }
  bool echo(bool enable) { return false; }
  void info() {}
  void verbose(bool enable) {}
  bool isVersionAtLeast(const char* versionString) { return false; }
  bool sendCommandCheckOK(const char cmd[]) { return false; }

  char buffer[65] = {};
};

class DummyEEProm {
public:
  DummyEEProm() {
    _header[0] = 'c';
    _header[1] = 'a';
    _header[2] = 'f';
    _header[3] = 'e';
    _header[4] = 1;

    // RTN, 19.Aug.2025
    // 30 1105
    // 60 1270
    // 90 1435
    // 120 1602
    // 150 1765
    _configData.rtnCoefficients[0] = 9.4440000000000009e+002f;
    _configData.rtnCoefficients[1] = 5.2730158730158729e+000f;
    _configData.rtnCoefficients[2] = 3.1746031746031746e-003f;
    _configData.rtnCoefficients[3] = -1.2345679012345678e-005f;

    // 30 1085 -25
    // 60 1245 -25
    // 90 1410 -25
    // 120 1585 -17
    // 150 1745 -20
    _configData.rtnBacklashCoefficients[0] = -2.6799999999999997e+001f;
    _configData.rtnBacklashCoefficients[1] = 3.1428571428571431e-002f;
    _configData.rtnBacklashCoefficients[2] = 1.5873015873015873e-004f;

    // LNG, 16.Aug.2025
    // 0 950
    // 10 1090
    // 20 1180
    // 40 1330
    // 60 1505
    // 70 1630
    _configData.lngCoefficients[0] = 9.5199345532256200e+002f;
    _configData.lngCoefficients[1] = 1.5448059970614935e+001f;
    _configData.lngCoefficients[2] = -2.3899425671160265e-001f;
    _configData.lngCoefficients[3] = 2.2417189795642862e-003f;
    _configData.lngBacklashCoefficients[0] = 0;
  }
  uint8_t read(int idx) {
    return idx < 5 ? _header[idx] : 0;
  }
  void write(int idx, uint8_t val) {
    if (idx < 5) {
      _header[idx] = val;
    }
  }
  void update(int idx, uint8_t val) {
    if (idx < 5) {
      _header[idx] = val;
    }      
  }
  CalibrationData_V1& get(int idx, CalibrationData_V1& config) {
    memcpy(&config, &_configData, sizeof(CalibrationData_V1));
    return config;
  }
  const CalibrationData_V1& put(int idx, const CalibrationData_V1& config) {
    memcpy(&_configData, &config, sizeof(CalibrationData_V1));
    return _configData;
  }
private:
  char _header[5];
  CalibrationData_V1 _configData;
};

class FakeServo {
public:
  void attach(uint8_t pin) {
    _pin = pin;
    std::cout << "FakeServo:attach([" << (short)pin << "])" << std::endl;
  }
  void write(uint16_t angle) const {
    std::cout << "FakeServo[" << _pin << "]:write([" << angle << "])" << std::endl;
  }
  void detach() {
    std::cout << "FakeServo:detach()" << std::endl;
  }
private:
  int _pin;
};

DummySerial logger;
using LogType = Singleton<DummySerial>;
template<> DummySerial& LogType::instance = logger;

DummySerial serial;
DummyBle ble;
DummyEEProm eeprom;

Messages messages;

nssm::SystemMonitorAo<LogType> systemMonitor(messages);
nspls::PulsWidthTransmitterAo<LogType, FakeServo, DummyEEProm> transmitter(messages, eeprom);
nstj::TrajectoryAo<LogType> trajectory(messages);
nsusb::UsbTerminalAo<LogType, DummySerial> usbTerminal(messages, serial);
nsble::BleTerminalAo<LogType, DummyBle> bleTerminal(messages, ble);
nsom::OverloadMonitorAo<LogType, DummyEEProm> overloadMonitor(messages, eeprom);
nssvc::ServiceAo<LogType, FakeServo, DummyEEProm> service(messages, eeprom);

void setup() {
}

void loop() {
  usbTerminal.load();
  bleTerminal.load();
  trajectory.load();
  transmitter.load();
  systemMonitor.load();
  overloadMonitor.load();
  service.load();

  usbTerminal.run();
  bleTerminal.run();
  trajectory.run();
  transmitter.run();
  systemMonitor.run();
  overloadMonitor.run();
  service.run();
}

void loop_thread() {
  while (true) {
    loop();
    this_thread::sleep_for(chrono::milliseconds(100));
  }
}

int main() {
  setup();
  thread st(&loop_thread);
  st.join();

  return 0;
}

/*
void move(TrajectoryData data);
void process();

int main() {

  std::cout << "Hello Smart Cards" << std::endl;

  for (int n = 0; n < 25; n++)
  {
    usbTerminal.load();
    bleTerminal.load();
    trajectory.load();
    transmitter.load();
    systemMonitor.load();
    overloadMonitor.load();
    service.load();

    usbTerminal.run();
    bleTerminal.run();
    trajectory.run();
    transmitter.run();
    systemMonitor.run();
    overloadMonitor.run();
    service.run();
  }

  move(TrajectoryData(TrajectoryInfo::ConnectD));
  move(TrajectoryData(TrajectoryInfo::Retract));
  move(TrajectoryData(TrajectoryInfo::ConnectB));

  messages.toTrajectoryQueue.push(TrajectoryData(TrajectoryInfo::Panic).raw);
  process();
}

void move(TrajectoryData data) {
  messages.toTrajectoryQueue.push(data.raw);
  messages.toSystemMonitorQueue.push(SystemStatusData(SystemStatusInfo::Moving).raw);

  process();
}
void process()
{
  for (int n = 0; n < 200; n++)
  {
    usbTerminal.load();
    bleTerminal.load();
    trajectory.load();
    transmitter.load();
    systemMonitor.load();
    overloadMonitor.load();

    usbTerminal.run();
    bleTerminal.run();
    trajectory.run();
    transmitter.run();
    systemMonitor.run();
    overloadMonitor.run();
  }
}
*/

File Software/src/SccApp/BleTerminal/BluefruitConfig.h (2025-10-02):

// COMMON SETTINGS
// ----------------------------------------------------------------------------------------------
// These settings are used in both SW UART, HW UART and SPI mode
// ----------------------------------------------------------------------------------------------
#define BUFSIZE 128        // Size of the read buffer for incoming data
#define VERBOSE_MODE true  // If set to 'true' enables debug output


// SOFTWARE UART SETTINGS
// ----------------------------------------------------------------------------------------------
// The following macros declare the pins that will be used for 'SW' serial.
// You should use this option if you are connecting the UART Friend to an UNO
// ----------------------------------------------------------------------------------------------
#define BLUEFRUIT_SWUART_RXD_PIN 9   // Required for software serial!
#define BLUEFRUIT_SWUART_TXD_PIN 10  // Required for software serial!
#define BLUEFRUIT_UART_CTS_PIN 11    // Required for software serial!
#define BLUEFRUIT_UART_RTS_PIN -1    // Optional, set to -1 if unused


// HARDWARE UART SETTINGS
// ----------------------------------------------------------------------------------------------
// The following macros declare the HW serial port you are using. Uncomment
// this line if you are connecting the BLE to Leonardo/Micro or Flora
// ----------------------------------------------------------------------------------------------
#ifdef Serial1  // this makes it not complain on compilation if there's no Serial1
#define BLUEFRUIT_HWSERIAL_NAME Serial1
#endif


// SHARED UART SETTINGS
// ----------------------------------------------------------------------------------------------
// The following sets the optional Mode pin, its recommended but not required
// ----------------------------------------------------------------------------------------------
#define BLUEFRUIT_UART_MODE_PIN 12  // Set to -1 if unused


// SHARED SPI SETTINGS
// ----------------------------------------------------------------------------------------------
// The following macros declare the pins to use for HW and SW SPI communication.
// SCK, MISO and MOSI should be connected to the HW SPI pins on the Uno when
// using HW SPI.  This should be used with nRF51822 based Bluefruit LE modules
// that use SPI (Bluefruit LE SPI Friend).
// ----------------------------------------------------------------------------------------------
#define BLUEFRUIT_SPI_CS 8
#define BLUEFRUIT_SPI_IRQ 7
#define BLUEFRUIT_SPI_RST 4  // Optional but recommended, set to -1 if unused

// SOFTWARE SPI SETTINGS
// ----------------------------------------------------------------------------------------------
// The following macros declare the pins to use for SW SPI communication.
// This should be used with nRF51822 based Bluefruit LE modules that use SPI
// (Bluefruit LE SPI Friend).
// ----------------------------------------------------------------------------------------------
#define BLUEFRUIT_SPI_SCK 13
#define BLUEFRUIT_SPI_MISO 12
#define BLUEFRUIT_SPI_MOSI 11

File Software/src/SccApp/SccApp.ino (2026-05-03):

#include <Arduino.h>
#include <Servo.h>
#include <HardwareSerial.h>
#include <EEPROM.h>
#include <SPI.h>
#include "Adafruit_BLE.h"
#include "Adafruit_BluefruitLE_SPI.h"
#include "Adafruit_BluefruitLE_UART.h"

#include "SystemMonitor/SystemMonitorAo.h"
#include "PulsWidthTransmitter/PulsWidthTransmitterAo.h"
#include "Trajectory/TrajectoryAo.h"
#include "UsbTerminal/UsbTerminalAo.h"
#include "BleTerminal/BleTerminalAo.h"
#include "OverloadMonitor/OverloadMonitorAo.h"
#include "Service/ServiceAo.h"
#include "Shared/Messages.h"
#include "Shared/Singleton.h"

void rtassert(bool condition) {
  digitalWrite(13, HIGH);
  if (condition) return;

  while (true) {
    Serial.println(F("rtassert - reboot required"));
    delay(1000);
  }
}

struct FakeLogger {
  void begin(uint16_t a) {}
  template<typename T>
  void print(T ch) {}
  template<typename T>
  void print(T ch, uint8_t mode) {}
  void println() {}
  template<typename T>
  void println(T ch) {}
  template<typename T>
  void println(T ch, uint8_t mode) {}
  operator bool() {
    return true;
  }
};
typedef Serial_ Logger_t;  // FakeLogger, HardwareSerial, Serial_
Logger_t logger;
using LogType = Singleton<Logger_t>;
template<> Logger_t& LogType::instance = logger;

Adafruit_BluefruitLE_SPI ble(BLUEFRUIT_SPI_CS, BLUEFRUIT_SPI_IRQ, BLUEFRUIT_SPI_RST);
Messages messages;

nssm::SystemMonitorAo<LogType> systemMonitor(messages);
nspls::PulsWidthTransmitterAo<LogType, Servo, EEPROMClass> transmitter(messages, EEPROM);
nstj::TrajectoryAo<LogType> trajectory(messages);
nsusb::UsbTerminalAo<LogType, Serial_> usbTerminal(messages, Serial);
nsble::BleTerminalAo<LogType, Adafruit_BluefruitLE_SPI> bleTerminal(messages, ble);
nsom::OverloadMonitorAo<LogType, EEPROMClass> overloadMonitor(messages, EEPROM);
nssvc::ServiceAo<LogType, Servo, EEPROMClass> service(messages, EEPROM);

void setup() {
  while (logger)
    ;
  logger.begin(9600);
}

void loop() {
  usbTerminal.load();
  bleTerminal.load();
  trajectory.load();
  transmitter.load();
  systemMonitor.load();
  overloadMonitor.load();
  service.load();

  usbTerminal.run();
  bleTerminal.run();
  trajectory.run();
  transmitter.run();
  systemMonitor.run();
  overloadMonitor.run();
  service.run();

  /*
  const float ArduinoVoltage = 3.3;
  int acsValueLng = analogRead(A0);
  int acsValueRtn = analogRead(A1);

   if (acsValueLng < 770 || /*acsValueRtn < 810 ||/ acsValueRtn > 820) {
    Serial.print(acsValueLng);
    Serial.print(" Rtn: ");
    Serial.println(acsValueRtn);
  }
  */
  //float acsValueF = (3.95 - (acsValue * (5.0 / 1024.0))) / 0.066;
  //Serial.println(acsValueF);

  delay(100);
}

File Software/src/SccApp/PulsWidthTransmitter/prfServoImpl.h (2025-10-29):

#ifndef prfServoImpl_h
#define prfServoImpl_h

#include <stdlib.h>
#include "prfServo2.h"
#include "../Shared/Messages.h"
#include "../Shared/BitCounter.h"
#include "../Shared/ConfigurationData.h"
#include "../Shared/ResourceStrings.h"

namespace nspls {

const uint8_t RTN_PIN = 12;
const uint8_t LNG_PIN = 11;
PRSDEFI(RSAO, "prfServoImpl");


template<class TLog, class TServo, class TEeprom>
class prfServoImpl : public prfServo2ImplBase<uint16_t> {
public:
  explicit prfServoImpl(TEeprom& eeprom)
    : _eeprom(eeprom) {
  }

  void begin() override {
    pinMode(RTN_PIN, OUTPUT);
    pinMode(LNG_PIN, OUTPUT);
  }

  void attachRtn() {
    _servoRtn.attach(RTN_PIN);
    _servoRtn.write(90);  // go to mid position of physical rotation axis
  }

  void attachLng() {
    _servoLng.attach(LNG_PIN);
    _servoLng.write(30);  // go to "zero" position of the physical rotation axis
  }

  void get(float** coefficients, float** backlashCoefficients) const final {

    char version = _eeprom.read(4);
    _log->print(F("Calibration Data Version "));
    _log->println(version == 1);
    if (version == 1) {
      CalibrationData_V1 calibrationData;

      _eeprom.get(5, calibrationData);

      coefficients[0][0] = calibrationData.rtnCoefficients[0];
      coefficients[0][1] = calibrationData.rtnCoefficients[1];
      coefficients[0][2] = calibrationData.rtnCoefficients[2];
      coefficients[0][3] = calibrationData.rtnCoefficients[3];

      backlashCoefficients[0][0] = calibrationData.rtnBacklashCoefficients[0];
      backlashCoefficients[0][1] = calibrationData.rtnBacklashCoefficients[1];
      backlashCoefficients[0][2] = calibrationData.rtnBacklashCoefficients[2];

      coefficients[1][0] = calibrationData.lngCoefficients[0];
      coefficients[1][1] = calibrationData.lngCoefficients[1];
      coefficients[1][2] = calibrationData.lngCoefficients[2];
      coefficients[1][3] = calibrationData.lngCoefficients[3];
      backlashCoefficients[1][0] = calibrationData.lngBacklashCoefficients[0];

      _log->println(F("Lng coefficients"));
      _log->println(calibrationData.lngCoefficients[0], 6);
      _log->println(calibrationData.lngCoefficients[1], 6);
      _log->println(calibrationData.lngCoefficients[2], 6);
      _log->println(calibrationData.lngCoefficients[3], 6);
      _log->println(F("Lng backlash coefficients"));
      _log->println(calibrationData.lngBacklashCoefficients[0], 6);
      _log->println(calibrationData.lngBacklashCoefficients[1], 6);
      _log->println(calibrationData.lngBacklashCoefficients[2], 6);
      _log->println(calibrationData.lngBacklashCoefficients[3], 6);
      _log->println(F("Rtn coefficients"));
      _log->println(calibrationData.rtnCoefficients[0], 6);
      _log->println(calibrationData.rtnCoefficients[1], 6);
      _log->println(calibrationData.rtnCoefficients[2], 6);
      _log->println(calibrationData.rtnCoefficients[3], 6);
      _log->println(F("Lng backlash coefficients"));
      _log->println(calibrationData.rtnBacklashCoefficients[0], 6);
      _log->println(calibrationData.rtnBacklashCoefficients[1], 6);
      _log->println(calibrationData.rtnBacklashCoefficients[2], 6);
      _log->println(calibrationData.rtnBacklashCoefficients[3], 6);
      _log->println(F("Rtn lower/upper thresholds"));
      _log->println(calibrationData.rtnOverflowLowerThreshold);
      _log->println(calibrationData.rtnOverflowUpperThreshold);
      _log->println(F("Lng lower/upper thresholds"));
      _log->println(calibrationData.lngOverflowLowerThreshold);
      _log->println(calibrationData.lngOverflowUpperThreshold);
      _log->println(F("-------------------"));
    } else {

      rs_println(RSAO, RSSTARTUP, RSUSEHARDCODEDVALUES);

      // https://arachnoid.com/polysolve/

      // RTN, 27. Oct. 2025
      // 30 1110
      // 60 1275
      // 90 1450
      // 120 1612
      // 150 1770
      coefficients[0][0] = 9.5240000000000009e+002f;
      coefficients[0][1] = 4.9912698412698422e+000f;
      coefficients[0][2] = 9.5238095238095229e-003f;
      coefficients[0][3] = -4.3209876543209875e-005f;

      // 30 1080 -30
      // 60 1235 -40
      // 90 1400 -50
      // 120 1570 -42
      // 150 1730 -40
      backlashCoefficients[0][0] = -1.2799999999999997e+001f;
      backlashCoefficients[0][1] = -6.7333333333333345e-001f;
      backlashCoefficients[0][2] = 3.3333333333333335e-003f;

      // LNG, 16.Aug.2025
      // 0 950
      // 10 1090
      // 20 1180
      // 40 1330
      // 60 1505
      // 70 1630
      coefficients[1][0] = 9.5199345532256200e+002f;
      coefficients[1][1] = 1.5448059970614935e+001f;
      coefficients[1][2] = -2.3899425671160265e-001f;
      coefficients[1][3] = 2.2417189795642862e-003f;
      backlashCoefficients[1][0] = 0;
    }
  }

  void write(uint8_t num, uint16_t servoVal) {
    //_logger.print(num);
    //_logger.print(F(" "));
    //_logger.println(servoVal);
    if (num == 0) {
      _servoRtn.write(servoVal);
    } else if (num == 1) {
      _servoLng.write(servoVal);
    }
  }

private:
  typename TLog::Type* _log = TLog::create();
  TEeprom& _eeprom;

  TServo _servoRtn;
  TServo _servoLng;
};

}

#endif

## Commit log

2025-10-02 Code first.
    [ConfigurationData.h]
2025-10-20 SketchUp models and Angular project.
    [SCC-AdjustmentRamp-Feet.skp, SCC-AdjustmentRamp.skp, SCC-Assemble1-Base.skp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]
2025-10-25 Add instructions, first draft.
    [SCC-Assemble4-RotationPlatform.skp]
2025-10-29 Store overflow protection threshold in EEPROM. Minor changes.
    [ConfigurationData.h]
2025-12-12 Add actions (#1)
    Add actions for MSBuild/MSTest and compile the Arduino sketches.
2026-10-22 Add overlaybutton library (#7)
    * Copied overlaybutton from LNR-Actuator and added it
    ---------
